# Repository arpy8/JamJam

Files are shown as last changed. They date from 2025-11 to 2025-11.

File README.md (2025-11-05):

<div align="center">
  
</div>

<h1> JamJam </h1>
Welcome to the *JamJam* repository! 🎉 Dive into the world of RF interference with this unique project based on the ESP32-C3 and NRF24 technology.

## 📚 Table of Contents
<!-- - [🎯 Possible Additions](#-possible-additions) -->
<!-- - [🚀 What Can You Do with This?](#-what-can-you-do-with-this) -->
- [📋 List of Components](#-list-of-components)
- [🧑‍🔧 Let's Get Started with Soldering!](#-lets-get-started-with-soldering)
- [📦 Flash Firmware](#-flash-firmware)
- [🎮 Device Control](#-device-control)
- [🌐 Web Interface](#-Web-Interface)
- [🎉 Final Outcome](#-final-outcome)
- [🙏 Acknowledgments](#-acknowledgments)

<!-- -----

## 🎯 Possible Additions
- **Deauthentication attack**
- **BLE spam**
- **Beacon spam**
- **nRF24 mousejack**

***`If you have the capability to assist with these features, please feel free to create pull requests!`***

----- -->

## 🚀 What Can You Do with This?
This jammer is built on the **ESP32-C3** architecture integrated with **configurable numbers of NRF24** modules. With its extraordinary capabilities, you can effectively disrupt signals across different technologies including:
- **Bluetooth** 🔊
- **BLE** 📱
- **Drones** 🚁
- **Wi-Fi** 📶
- **Zigbee**📡

-----

## 📋 List of Components
To bring this project to life, you will need the following components:

| Name | Designator | Link (Robu) | Quantity | Unit Price (₹) | Amount (₹) |
|---|---|---|---|---|---|
| 100nF | C1 | [TCC0805X7R104K101DT – CCTC 100nF Capacitor](https://robu.in/product/tcc0805x7r104k101dt-cctc-smt-ceramic-capacitors-0805-x7r-104k100nf%c2%b110-rated-voltage100v-thickness0-85mmtape/) | 2 | 6 | 12 |
| ESP32-C3 Development Board with Soldering | MCU | [ESP32-C3 Development Board](https://robu.in/product/esp32-c3-development-board-with-soldering/) | 1 | 257 | 257 |
| 0.91 inch 128×32 Blue OLED Display Module with I2C/IIC Serial Interface | OLED | [Blue OLED Display Module](https://robu.in/product/blue-oled-display-module/) | 1 | 144 | 144 |
| 2.4GHz NRF24L01+PA+LNA SMA Wireless Transceiver Antenna | NRF1, NRF2 | [NRF24L01+PA+LNA Module](https://robu.in/product/2-4ghz-nrf24l01palna-sma-antenna-wireless-transceiver-communication-module-1km/) | 2 | 135 | 270 |

-----

## 🧑‍🔧 Let's Get Started with Soldering!
<div style="margin-left: 20px;">

### Connecting First nRF24 module
| **Pin Name** | **ESP32 GPIO** | **Connection** |
|---|---|---|
| VCC | 3.3V | (+) capacitor |
| GND | GND | (-) capacitor |
| CE | GPIO 13 | |
| CSN | GPIO 14 | |
| SCK | GPIO 12 | |
| MISO | GPIO 5 | |
| MOSI | GPIO 6 | |
| IRQ | | |

### Connecting Second nRF24 module
| **Pin Name** | **ESP32 GPIO** | **Connection** |
|---|---|---|
| VCC | 3.3V | (+) capacitor |
| GND | GND | (-) capacitor |
| CE | GPIO 15 | |
| CSN | GPIO 16 | |
| SCK | GPIO 12 | |
| MISO | GPIO 5 | |
| MOSI | GPIO 6 | |
| IRQ | | |

### OLED Connection
| **Pin Name** | **ESP32 GPIO** |
|---|---|
| VCC | 3.3V |
| GND | GND |
| SDA | GPIO 8 |
| SCL | GPIO 9 |

### Button Connection
| **Button Actions** | **ESP32 GPIO** |
|---|---|
| OK | GPIO 20 |
| NEXT | GPIO 10 |
| PREVIOUS | GPIO 21 |

### Schematic
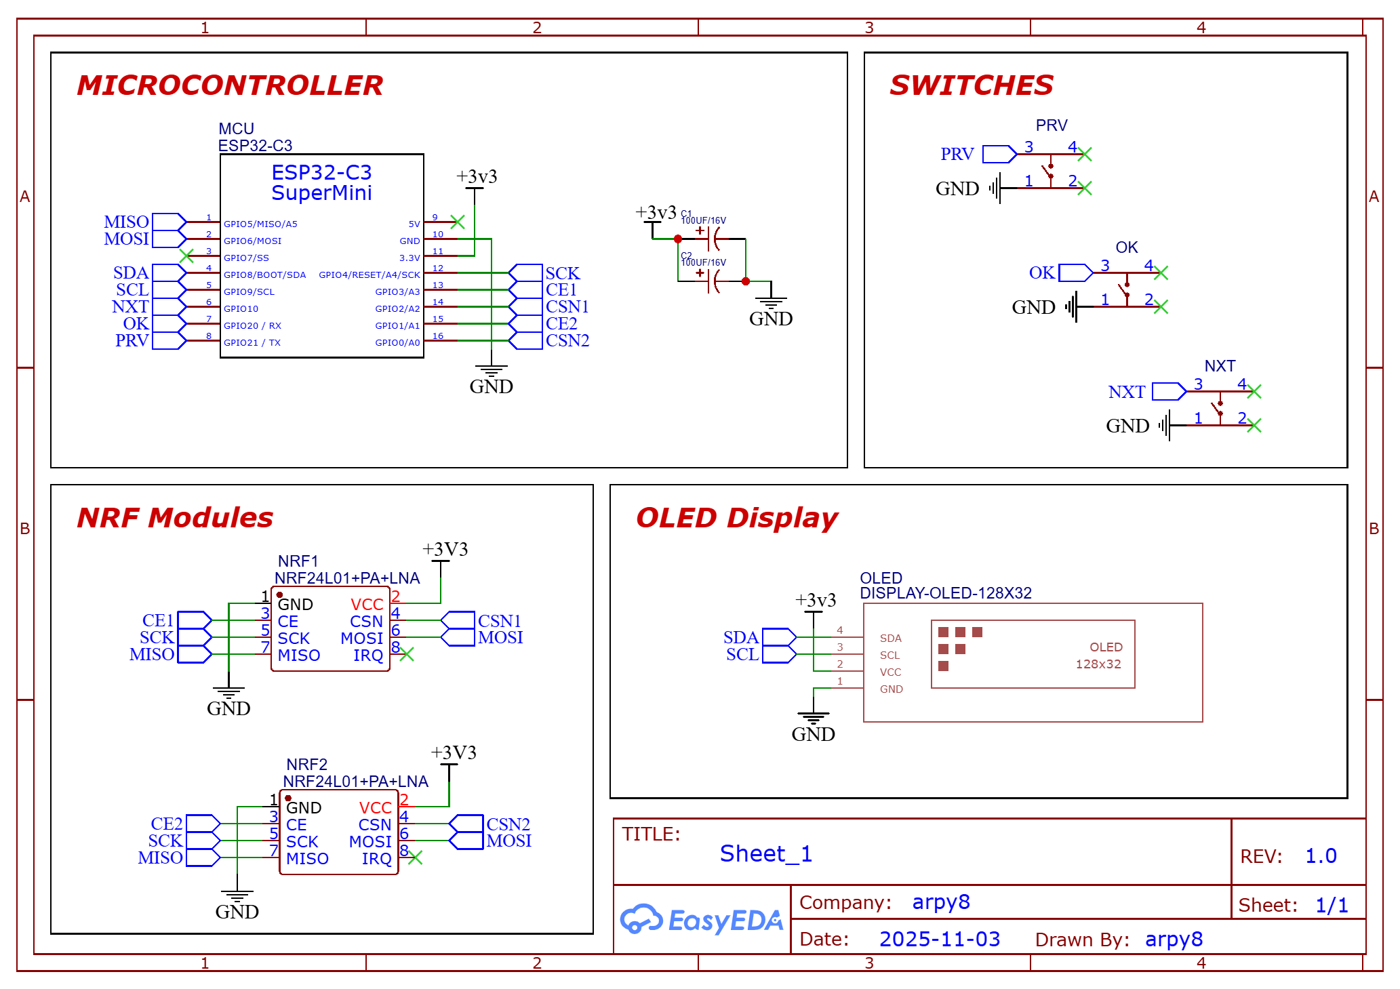
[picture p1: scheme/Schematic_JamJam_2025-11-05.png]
schematic


</div>

-----

## 📦 Flash Firmware
<details>
<summary><strong>Manual Update</strong></summary>

<div style="margin-left: 20px;">

Follow these steps to flash the firmware:
1. Download the firmware from the **[releases](https://github.com/W0rthlessS0ul/nRF24_jammer/releases)** section that corresponds to your display.
2. Navigate to **ESPWebTool**: [ESPWebTool](https://esp.huhn.me/)
3. Arrange the files as per the table below:

| **Address** | **File Name** |
|---|---|
| 0x1000 | nRF24_jammer_bootloader.bin |
| 0x8000 | nRF24_jammer_partitions.bin |
| 0x10000 | nRF24_jammer.bin |

4. Click "Flash," and once the installation is complete, **restart your board** and enjoy using your jammer!

flash

</div>
</details>
<details>
<summary><strong>OTA upgrade</strong></summary>

<div style="margin-left: 20px;">

### This method can only be used if you have firmware version 1.9 or higher installed.
Follow these steps to flash the firmware:
1. Download the firmware from the **[releases](https://github.com/W0rthlessS0ul/nRF24_jammer/releases)** section that corresponds to your display.
2. Turn on your device and open a web browser
3. Navigate to the web interface at **192.168.4.1**
4. Click on "**OTA**" and select the file "**nRF24_jammer.bin**" (`⚠️️ make sure not to choose the bootloader or partitions files`).

</div>
</details>

-----

## 🎮 Device Control 

<div style="margin-left: 20px;">

#### 📋 Menu Navigation
- **OK button** short press → Select menu item
- **Next button** short press → Next menu item
- **Previous button** short press → Previous menu item

#### 📡 Misc Jammer
- **OK button** short press → Select channel
- **Next button** short press → Channel +1
- **Next button** long press → Continuous channel +1 (every 100ms)
- **Previous button** short press → Channel -1
- **Previous button** long press → Continuous channel -1 (every 100ms)

</div>

> **Single press** stops active attacks

-----

## 🌐 Web Interface

- To utilize the web interface, please follow the steps outlined below.
1. activate the **nRF24 jammer**.
2. Connect to the Wi-Fi network named `JamJam` using the password `poopoo`.
3. open your web browser and navigate to the IP address `192.168.4.1`.
4. Now you can control your nRF24 jammer through an web interface.

web_interface

-----

## 🎉 Final Outcome

### CAD Model (To be printed)
|Closed|Open|
|-|-|
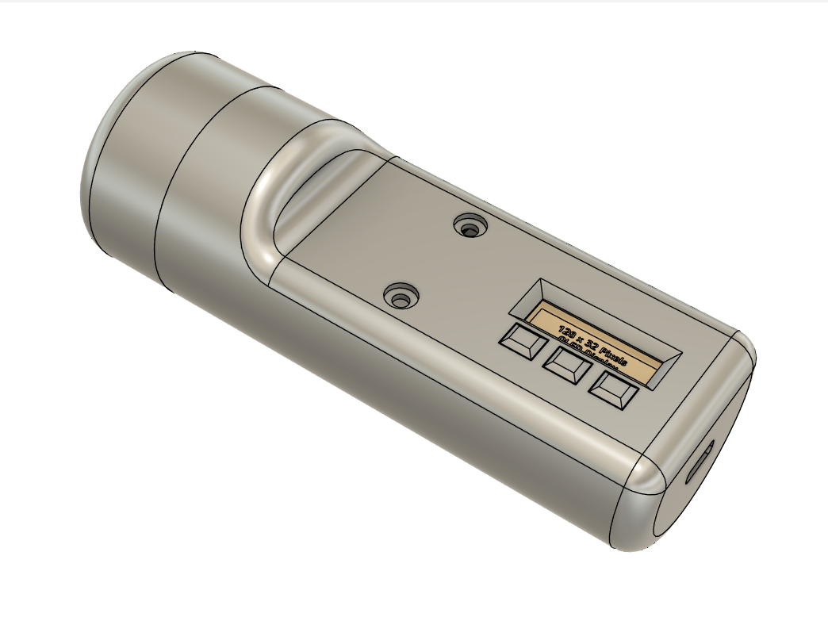
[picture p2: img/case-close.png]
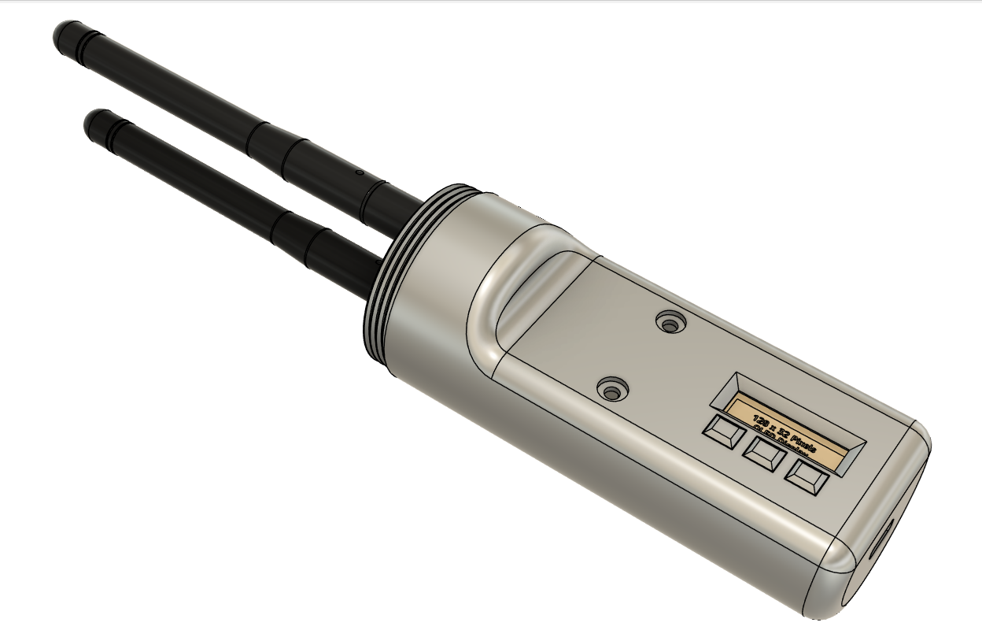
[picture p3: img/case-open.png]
|||

### Normal Spectrum
Normal Spectrum

### Bluetooth Jam Spectrum
Bluetooth Jam Spectrum

### Drone Jam Spectrum
Drone Jam Spectrum

### Wi-Fi Jam Spectrum
Wi-Fi Jam Spectrum

### BLE Jam Spectrum
BLE Jam Spectrum

### Zigbee Jam Spectrum
Zigbee Jam Spectrum

-----

## 🙏 Acknowledgments
- [W0rthlessS0ul](https://github.com/W0rthlessS0ul)

-----

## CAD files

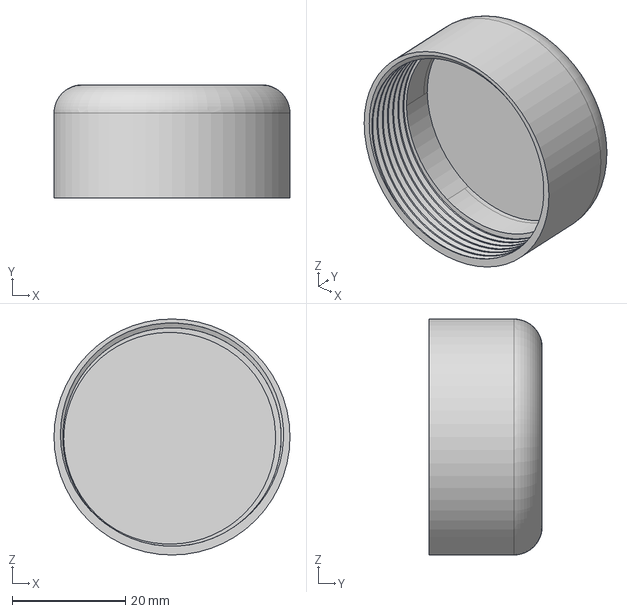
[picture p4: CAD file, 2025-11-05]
cad/Lid_JamJam.step
41.6 x 20.0 x 41.6 mm

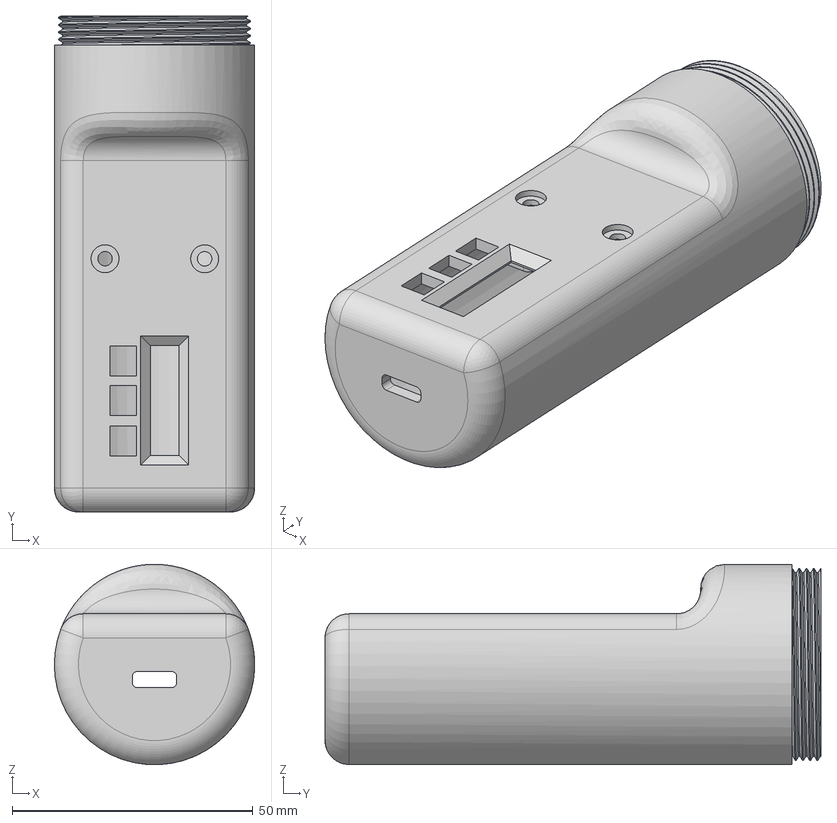
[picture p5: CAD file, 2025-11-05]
cad/Case_JamJam.step
41.6 x 103.0 x 41.6 mm

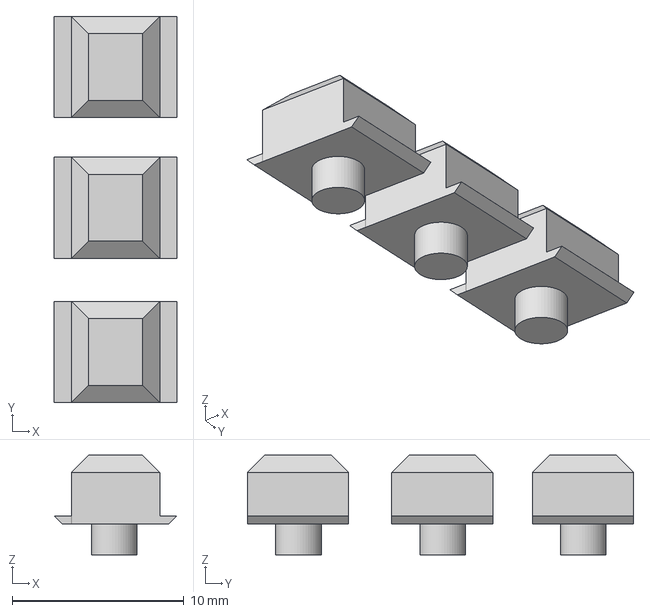
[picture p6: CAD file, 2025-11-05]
cad/Button-Caps_JamJam.step
7.14 x 22.5 x 5.80 mm

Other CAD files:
cad/Button-Caps_JamJam.stl
cad/Case_JamJam.stl
cad/Lid_JamJam.stl

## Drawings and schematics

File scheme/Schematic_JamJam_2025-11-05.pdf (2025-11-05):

A | A

1

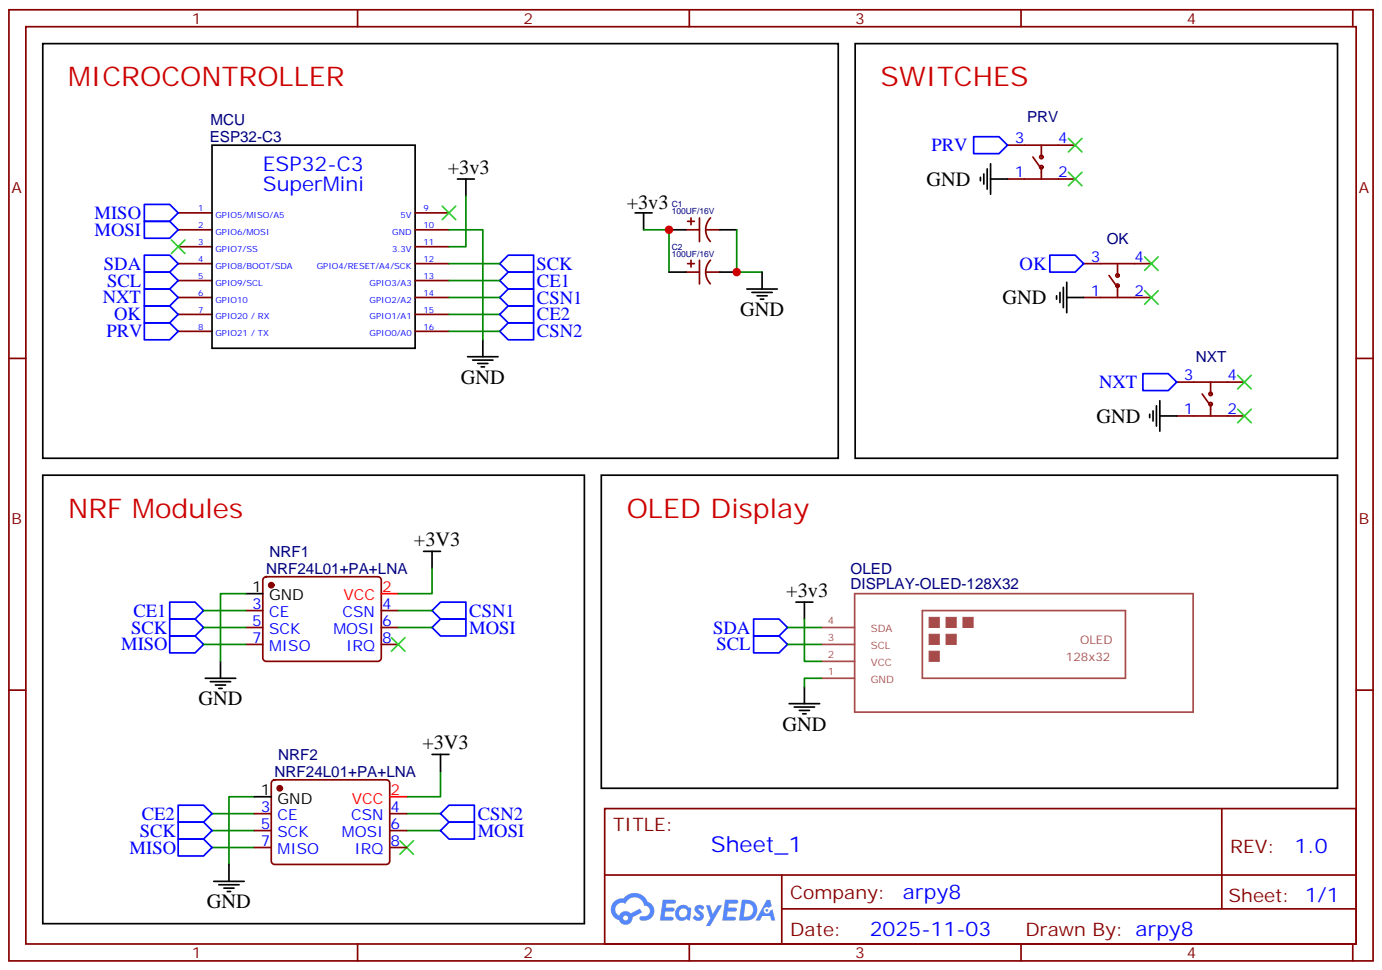
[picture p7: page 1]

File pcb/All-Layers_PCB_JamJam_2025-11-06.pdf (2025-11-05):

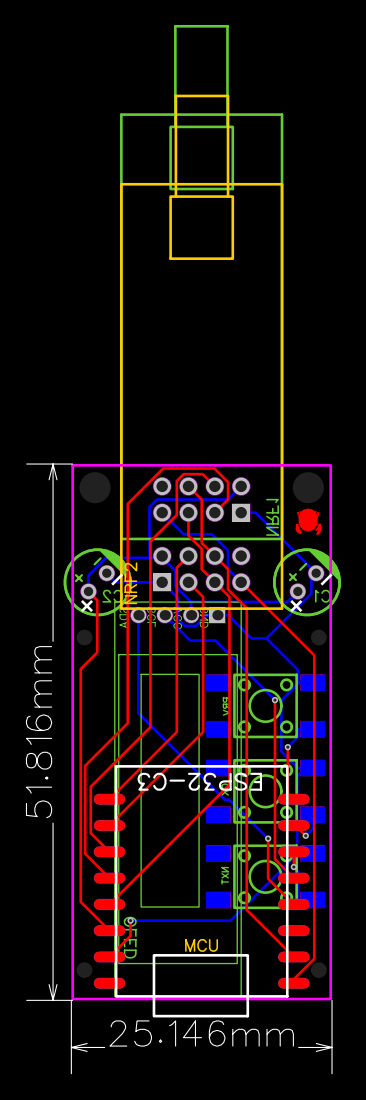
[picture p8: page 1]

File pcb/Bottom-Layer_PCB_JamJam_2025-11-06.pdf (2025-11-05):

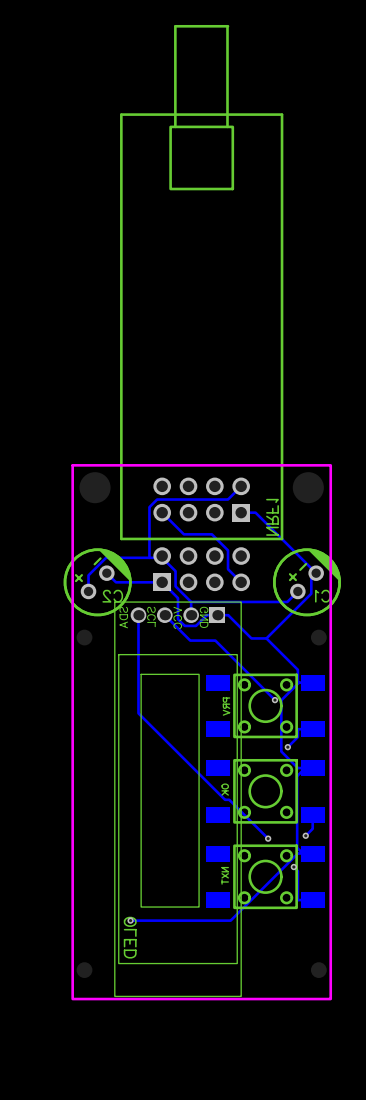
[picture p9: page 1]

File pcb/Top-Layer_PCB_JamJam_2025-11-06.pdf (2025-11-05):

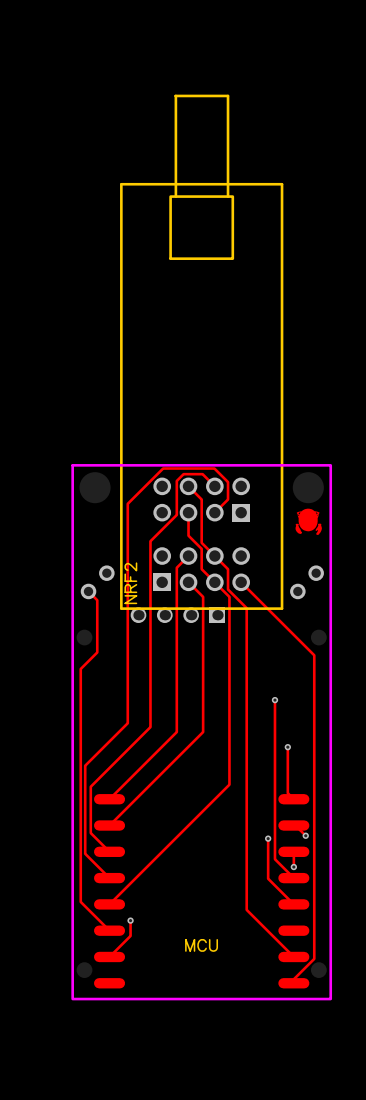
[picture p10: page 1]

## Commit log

2025-11-05 प्रथम कमिट
    [BOM.csv, Button-Caps_JamJam.step, Button-Caps_JamJam.stl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]
2025-11-05 पठनार्थं पत्रम् अद्यतनं कुरु।
